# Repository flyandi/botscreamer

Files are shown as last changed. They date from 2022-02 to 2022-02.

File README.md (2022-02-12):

```
______  _____ _____ _____ _____ ______ _____  ___  ___  ___ ___________
| ___ \|  _  |_   _/  ___/  __ \| ___ \  ___|/ _ \ |  \/  ||  ___| ___ \
| |_/ /| | | | | | \ `--.| /  \/| |_/ / |__ / /_\ \| .  . || |__ | |_/ /
| ___ \| | | | | |  `--. \ |    |    /|  __||  _  || |\/| ||  __||    /
| |_/ /\ \_/ / | | /\__/ / \__/\| |\ \| |___| | | || |  | || |___| |\ \
\____/  \___/  \_/ \____/ \____/\_| \_\____/\_| |_/\_|  |_/\____/\_| \_|
```

This is the firmware and associated files for the Botscreamer as seen on Botgrinder TV.

The Botscreamer is a tiny 3W speaker system that reacts on the attitude of your quad and is light enough to be mounted on top of your lipo. Did I say it's loud? It's freaking loud! 

It comes with 4 pre-loaded sounds (simple 16bit PCM wav files) and even has a music maker mode that reacts on yaw (14 notes across 360 degrees).

See it in action here https://www.youtube.com/watch?v=8f52Pep6f3Y

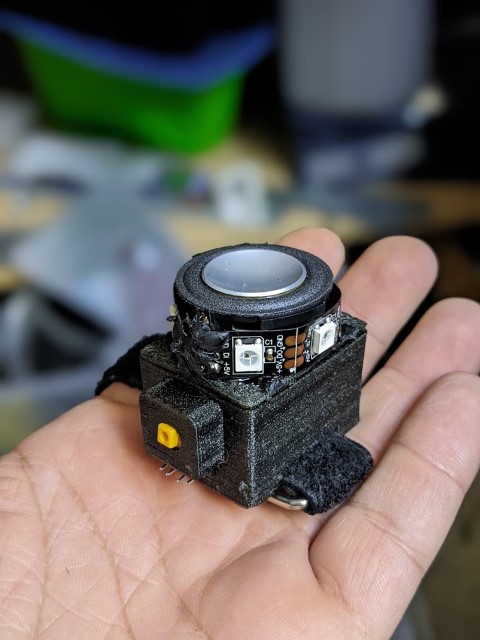
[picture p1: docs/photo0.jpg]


# Build it

Get the parts below:

1x ESP8266 Mini D1 (https://amzn.to/34F7Ud2)

1x MAX98357 I2S amplifier (https://amzn.to/3rzCkqs)

1x 4ohm/3w speaker with a large magnet (https://amzn.to/3Hz32op)

1x Tactile button 

1x 10k resistor (for the button)

1x 4-wire that connects to your FC

If you want LED lights, you also need a some WS8212 RGB LED's.

# Wire up

See the picture below how to wire everything up. This expects you used the parts above.

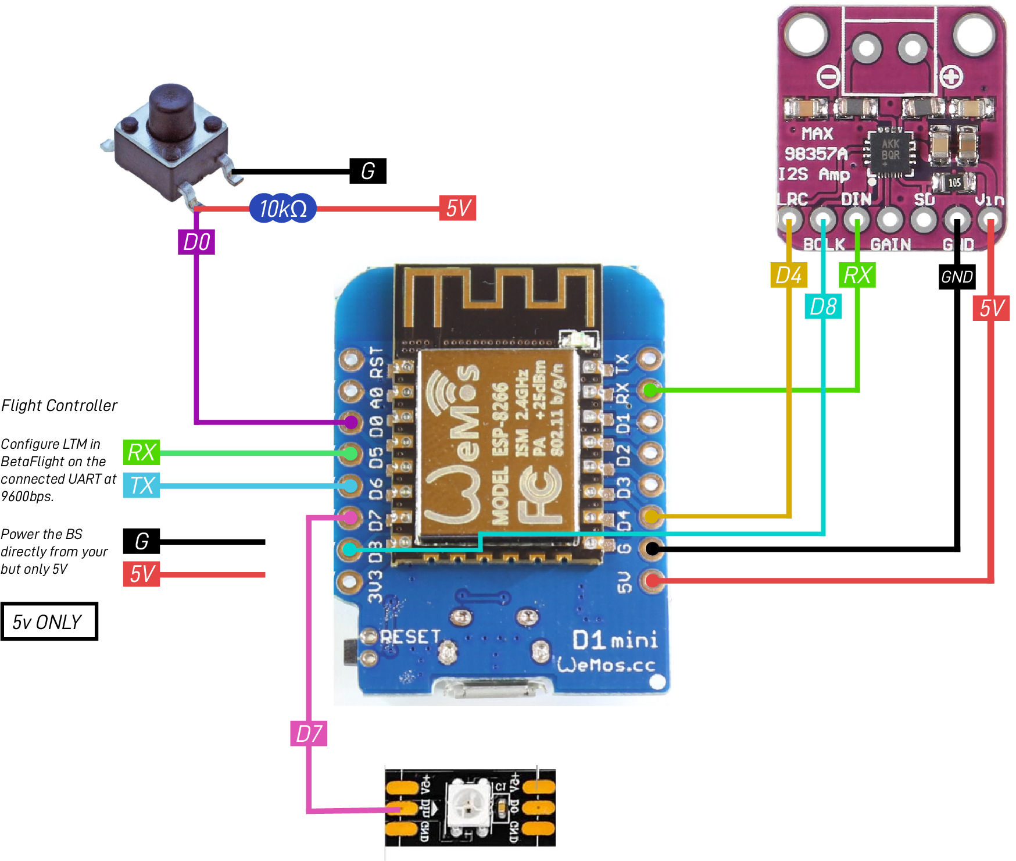
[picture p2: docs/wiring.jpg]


## WARNING

Make sure you power the ESP8266 ONLY with 5V or you will burn the ESP8266.

# Print it

There is a case in the `/3d` folder that fits all parts. Print with TPU95 with 20% infill to keep it light but still strong. The PCB material will stiffen it up. The case has cut outs on the bottom allowing you to use a up to 20mm strap.

# Deploy it

Use the Arduino IDE to deploy the code to the ESP8266 and use the SPIFFS tool to upload the files. RandomNerdTutorials has way better explanation than I could do, so head over to https://randomnerdtutorials.com/install-esp8266-filesystem-uploader-arduino-ide/ to learn more how to do that.

If you haven't actually installed the ESP8266 board definitions you need to use the Arduino IDE Platform Manager to install the ESP8266. Once again RDT has you covered at https://randomnerdtutorials.com/how-to-install-esp8266-board-arduino-ide/

There are a few libraries needed that can be downloaded via the Arduino IDE Library Manager:

+ Adafruit NeoPixel Library
+ ESP8266Audio Library

Once done, hook up your ESP8266 and upload it. 

# Configuration

There are some configurations that I explained in the code itself. Check it there.

# Fly it

There are 4 modes selectable through the button and the fifth mode is the music maker mode. Most modes have a minimum requirement of 1.2s in order to work which prevents false triggers. So you have to hold it for a least that time in order to enable.

| Mode | What | Comment | 
| ----  | --- | --- |
| 1 | Goat | Screams like a goat on roll (upside down) | 
| 2 | Human | Scary lady screaming like no other day on roll (upside down) |
| 3 | Duck | A rapid duck noise on roll (upside down) |
| 4 | Police | Police lights mode. Pitch forward to turn on sound and pitch backward to turn it off |
| 5 | Music Maker Mode | See below |

# Music Maker Mode

In Music Maker Mode the BS is playing a continues sound that can be modified using YAW. It plays 14 notes across the 360 degree. It runs on a static 100bpm so you have about 600ms to turn your quad to modify the sound which is plenty enough. 

`Make some tunez!`

# Audio Files

All audio files used are standard 16bit PCM encoded wave files with no compressions. Keep it short as the ESP8266 has about 2.5MB useable space. I recommend to keep it under 3s per audio file.

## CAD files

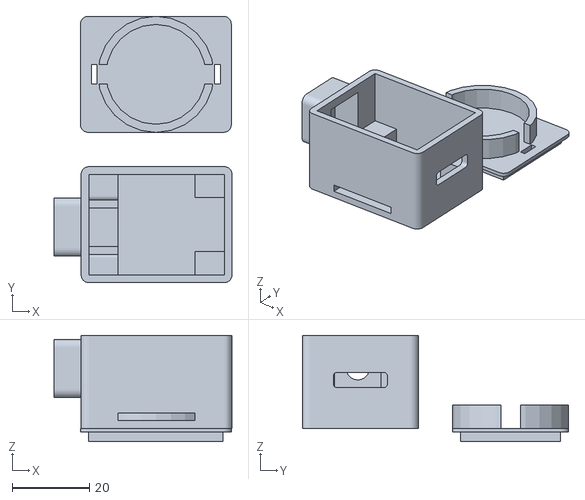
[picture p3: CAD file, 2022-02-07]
3d/case.stl
46.0 x 68.8 x 27.4

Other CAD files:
3d/case.skp

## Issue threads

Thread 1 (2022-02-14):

3d Files

jsimmo1, 2022-02-14:
Can't get get Cura or Sketchup to recognize the files.   Please check them.

flyandi, 2022-02-15:
Hmm.. I just loaded the STL straight into Cura without issues. I am on version 4.8.0

The Sketchup file is in 2021 and pre-2021 format.

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

jsimmo1, 2022-02-15:
Got it.   I had tried to download in Safari by using the download link file option instead of clicking on the stl file and then clicking on the download button which works.  Thanks for the response.

Closed 2022-02-15.

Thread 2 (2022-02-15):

Input voltage

mkvug, 2022-02-15:
Not really an issue, but I wasn't sure how else to ask and I figured this way others will see the answer. The ESP8266 says it takes 3.3v in, but you are showing 5v in. I can't find anything online that suggests the ESP8266 can handle 5v in. Am I missing something? Or are you actually using 3.3v?

flyandi, 2022-02-18:
Most ESP8266 dev boards expose a 5V pin .. but yeah I prefer the Wemos D1 because it's cheap and ready available and has the smallest footprint. They are smaller boards available but they are hard to come by.

Closed 2022-02-18.

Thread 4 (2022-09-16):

I cant make it work :( Photos and details

bloodf, 2022-09-16:
Hi, I loved the idea of the screamer. I've bought everything needed to do it, flashed the ESP, and soldered everything according to the schema. But When connected to the drone, it doesn't do anything. The ESP flashes blue (not a solid blue), and there is no sound :(

The 5V and G go
 from the drone to the board and the amplifier, the switch gets fed from the same connection using the resistor to the required port.

 The Arduino IDE flashes the board correctly and doesn't give any error.

 Is there any way to debug this?

 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

ray940, 2022-12-16:
Betaflight?

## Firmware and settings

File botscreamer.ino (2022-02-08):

/*
______  _____ _____ _____ _____ ______ _____  ___  ___  ___ ___________
| ___ \|  _  |_   _/  ___/  __ \| ___ \  ___|/ _ \ |  \/  ||  ___| ___ \
| |_/ /| | | | | | \ `--.| /  \/| |_/ / |__ / /_\ \| .  . || |__ | |_/ /
| ___ \| | | | | |  `--. \ |    |    /|  __||  _  || |\/| ||  __||    /
| |_/ /\ \_/ / | | /\__/ / \__/\| |\ \| |___| | | || |  | || |___| |\ \
\____/  \___/  \_/ \____/ \____/\_| \_\____/\_| |_/\_|  |_/\____/\_| \_|
ENVISIONED BY BOTGRINDER AND CREATED BY FLY&I
Learn more at https://github.com/flyandi/botscreamer or https://flyandi.net

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
THE SOFTWARE IS PROVIDED "AS IS", WITHOUT WARRANTY OF ANY KIND, EXPRESS OR
IMPLIED, INCLUDING BUT NOT LIMITED TO THE WARRANTIES OF MERCHANTABILITY,
FITNESS FOR A PARTICULAR PURPOSE AND NONINFRINGEMENT. IN NO EVENT SHALL THE
AUTHORS OR COPYRIGHT HOLDERS BE LIABLE FOR ANY CLAIM, DAMAGES OR OTHER LIABILITY,
WHETHER IN AN ACTION OF CONTRACT, TORT OR OTHERWISE, ARISING FROM, OUT OF OR IN
CONNECTION WITH THE SOFTWARE OR THE USE OR OTHER DEALINGS IN THE SOFTWARE.
*/

// -----------------------------------------------------------------------
// configuration, calibration

// Volume, 0 is off, 0.1 - 3.99 where 3.99 is the loudest possible
#define VOLUME 3.99

// Roll rate is used to determinated upside down flying
// Upside down is true when the value is < ROLL_LOW || > ROLL_HIGH,
#define ROLL_LOW -160 // -160 degree is the default
#define ROLL_HIGH 160 // 160 degree is the default

// Pitch rate is used to enable/disable certain functions
// Pitching forward enables it, and pitching backwards disables it
// Becomes true if it's within the range of min and max
#define PITCH_MIN 40
#define PITCH_MAX 60

// disable for production use
//#define DEBUG

// -----------------------------------------------------------------------
// DO NOT CHANGE ANYTHING BEYOND THIS PART
// ONLY IF YOU KNOW WHAT YOU DOING!

// includes
#include "ESP8266WiFi.h"
#include "AudioFileSourceSPIFFS.h"
#include "AudioFileSourcePROGMEM.h"
#include "AudioGeneratorRTTTL.h"
#include "AudioGeneratorWAV.h"
#include "AudioOutputI2S.h"
#include <SoftwareSerial.h>
#include <Adafruit_NeoPixel.h>

// ltm config
#define LTM_RX_PIN D5
#define LTM_TX_PIN D6
#include "ltm.h"

// button config
#define BUTTON_PIN D0
#define BUTTON_MIN 300

// led config
#define LED_PIN D7
#define LED_PIXELS 6
#define LED_BRIGHTNESS 255

#define LED_PROGRAM_DEFAULT 0
#define LED_PROGRAM_POLICE 1
#define LED_PROGRAM_HUE_HEADING 2

// on selector
#define ON_ROLL 0
#define ON_ROLL_TIMER 1200 // at least keep it 1.2 seconds upside down
#define ON_PITCH 1
#define ON_HEADING 2

// actual modes
//
struct
{
  char *file;
  uint8_t on;
  bool loop;
  uint8_t led_program;
  uint16_t led_time;
} MODES[] = {
    {"/goat.wav", ON_ROLL, false, LED_PROGRAM_DEFAULT, 50},
    {"/human.wav", ON_ROLL, false, LED_PROGRAM_DEFAULT, 50},
    {"/goose.wav", ON_PITCH, false, LED_PROGRAM_HUE_HEADING, 50},
    {"/police.wav", ON_PITCH, true, LED_PROGRAM_POLICE, 120},
    {"", ON_HEADING, true, LED_PROGRAM_HUE_HEADING, 50},
};

#define NUM_MODES 5
#define MODE_SYNTH 4

// synth
const char *SYNTH_NOTES[] = {
    "a",
    "b",
    "c",
    "d",
    "e",
    "f",
    "g",
    "a#",
    "b#",
    "c#",
    "d#",
    "e#",
    "f#",
    "g#"};

#define NUM_SYNTH_NOTES 14

// locals
AudioGeneratorWAV *wav;
AudioFileSourceSPIFFS *file;
AudioFileSourcePROGMEM *rts;
AudioOutputI2S *out;
AudioGeneratorRTTTL *rtttl;
Adafruit_NeoPixel pixels(LED_PIXELS, LED_PIN, NEO_GRB + NEO_KHZ800);

bool button_p = false;
bool led_enabled = true;
bool on_enabled = false;
uint8_t mode = 0;
uint16_t led_state = 0;
uint32_t button_t = 0;
uint32_t led_t = 0;
uint32_t on_t = 0;

#ifdef DEBUG
uint32_t debug_t = 0;
#endif

// setup
void setup()
{
  // start with pixels
  pixels.begin();
  pixels.show();
  pixels.setBrightness(LED_BRIGHTNESS);
  wipe(0xFF0000, true);

  // boot up
  WiFi.forceSleepBegin();
  Serial.begin(115200);
  pinMode(BUTTON_PIN, INPUT);
  pinMode(LED_BUILTIN, OUTPUT);
  out = new AudioOutputI2S();
  wav = new AudioGeneratorWAV();
  rtttl = new AudioGeneratorRTTTL();
  out->SetGain(VOLUME);
  ltm_begin();

  // cleanup
  delay(1000);
  wipe(0x00FF00, true);
  delay(1000);
}

// wipe
void wipe(uint32_t color, bool show)
{
  for (int i = 0; i < pixels.numPixels(); i++)
  {
    pixels.setPixelColor(i, color);
  }
  if (show)
  {
    pixels.show();
  }
}

// audio
void audio()
{
  if (rtttl->isRunning())
  {
    rtttl->stop();
  }
  if (wav->isRunning())
  {
    wav->stop();
  }
  if (mode != MODE_SYNTH)
  {
    file = new AudioFileSourceSPIFFS(MODES[mode].file);
    wav->begin(file, out);
  }
}

// cycle_mode
void cycle_mode()
{
  mode += 1;
  if (mode >= NUM_MODES)
  {
    mode = 0;
  }
  led_state = 0;
  on_enabled = false;
  audio();
}

// audio_loop
void audio_loop()
{
  if (mode == MODE_SYNTH)
  {
    if (rtttl->isRunning())
    {
      if (!rtttl->loop())
      {
        rtttl->stop();
      }
    }
    else
    {

      char tone[32];
      uint8_t note = map(LTM_DATA.heading, 0, 360, 0, NUM_SYNTH_NOTES - 1);
      if (note < 0 || note >= NUM_SYNTH_NOTES)
      {
        note = 0;
      }
      strcat(tone, "A:d=4,o=1,b=120:");
      strcat(tone, SYNTH_NOTES[note]);
#ifdef DEBUG
      Serial.printf("Note: heading %d / note %d %s\n", LTM_DATA.heading, note, SYNTH_NOTES[note]);
#endif
      rts = new AudioFileSourcePROGMEM(tone, strlen_P(tone));
      rtttl->begin(rts, out);
    }
    return;
  }

  if (wav->isRunning())
  {
    if (!wav->loop())
    {
      wav->stop();
      if (MODES[mode].loop && on_enabled)
      {
        audio();
      }
    }
  }
  else
  {

    if (on_enabled)
    {
      audio();
    }
  }
}

// process_loop
void process_loop()
{
  if (MODES[mode].on == ON_ROLL)
  {
    if ((LTM_DATA.roll > ROLL_HIGH && LTM_DATA.roll < 360) || (LTM_DATA.roll < ROLL_LOW && LTM_DATA.roll > -360))
    {
      if (on_t == 0)
      {
        on_t = millis();
      }
      else
      {
        if (millis() - on_t > ON_ROLL_TIMER)
        {
          on_enabled = true;
          on_t = 0;
        }
      }
    }
    else
    {
      on_enabled = false;
    }
  }

  if (MODES[mode].on == ON_PITCH)
  {
    if (!on_enabled && LTM_DATA.pitch > PITCH_MIN && LTM_DATA.pitch < PITCH_MAX)
    {
      on_enabled = true;
    }
    else if (on_enabled && LTM_DATA.pitch < -1 * PITCH_MIN && LTM_DATA.pitch > -1 * PITCH_MAX)
    {
      on_enabled = false;
    }
  }

#ifdef DEBUG
  if (millis() - debug_t > 250)
  {
    Serial.printf("P %d / R %d / H %d / ON %d\n", LTM_DATA.pitch, LTM_DATA.roll, LTM_DATA.heading, on_enabled);
    debug_t = millis();
  }
#endif
}

// led_loop
void led_loop()
{
  if (millis() - led_t > MODES[mode].led_time)
  {
    if (MODES[mode].led_program == LED_PROGRAM_POLICE)
    {
      wipe(0x000000, false);

      if (led_state == 0 || led_state == 2)
      {
        pixels.setPixelColor(0, 0xFF0000);
        pixels.setPixelColor(1, 0xFF0000);
        pixels.setPixelColor(2, 0xFF0000);
      }
      if (led_state == 4 || led_state == 6)
      {
        pixels.setPixelColor(3, 0x0000FF);
        pixels.setPixelColor(4, 0x0000FF);
        pixels.setPixelColor(5, 0x0000FF);
      }
      led_state += 1;
      if (led_state > 7)
      {
        led_state = 0;
      }
    }

    if (MODES[mode].led_program == LED_PROGRAM_DEFAULT)
    {
      if (wav->isRunning())
      {
        wipe(led_state % 2 != 0 ? pixels.ColorHSV((65536L / 32) * led_state) : 0x000000, false);
        led_state += 1;
        if (led_state > 512)
        {
          led_state = 0;
        }
      }
      else
      {
        wipe(0x000000, false);
      }
    }

    if (MODES[mode].led_program == LED_PROGRAM_HUE_HEADING)
    {
      wipe(pixels.ColorHSV((65536L / 360) * LTM_DATA.heading), false);
    }

    // general
    pixels.show();
    led_t = millis();
  }
}

// button_loop
void button_loop()
{
  bool button = !digitalRead(BUTTON_PIN);
  if (button && !button_p)
  {
    button_p = true;
    button_t = millis();
  }
  else if (!button && button_p)
  {
    button_p = false;
    if (millis() - button_t > BUTTON_MIN)
    {
      cycle_mode();
    }
  }
}

// loop
void loop()
{
  ltm_loop();
  audio_loop();
  process_loop();
  button_loop();
  led_loop();
}

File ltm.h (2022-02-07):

/*
 ____  __    _  _  __
(  __)(  )  ( \/ )/ _\
 ) _) / (_/\ )  //    \
(__)  \____/(__/ \_/\_/

This file is part of the FLYA Firmware. Learn more at https://flyandi.net/flya
Copyright 2021 FLY&I (FLYANDI.NET)

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
THE SOFTWARE IS PROVIDED "AS IS", WITHOUT WARRANTY OF ANY KIND, EXPRESS OR
IMPLIED, INCLUDING BUT NOT LIMITED TO THE WARRANTIES OF MERCHANTABILITY,
FITNESS FOR A PARTICULAR PURPOSE AND NONINFRINGEMENT. IN NO EVENT SHALL THE
AUTHORS OR COPYRIGHT HOLDERS BE LIABLE FOR ANY CLAIM, DAMAGES OR OTHER LIABILITY,
WHETHER IN AN ACTION OF CONTRACT, TORT OR OTHERWISE, ARISING FROM, OUT OF OR IN
CONNECTION WITH THE SOFTWARE OR THE USE OR OTHER DEALINGS IN THE SOFTWARE.
*/

#ifndef _H_LTM_
#define _H_LTM_

#include <SoftwareSerial.h>

#ifndef LTM_RX_PIN
#error LTM has no RX pin defined
#endif

#ifndef LTM_TX_PIN
#error LTM has no TX pin defined
#endif

#ifndef LTM_BAUD
#define LTM_BAUD 9600
#endif

enum
{
    LTM_IDLE,
    LTM_HEADER_START1,
    LTM_HEADER_START2,
    LTM_HEADER_MSGTYPE,
    LTM_HEADER_DATA
};

#define LTM_LONGEST_FRAME_LENGTH 18
#define LTM_GFRAMELENGTH 18
#define LTM_AFRAMELENGTH 10
#define LTM_SFRAMELENGTH 11
#define LTM_OFRAMELENGTH 18
#define LTM_NFRAMELENGTH 10
#define LTM_XFRAMELENGTH 10

const char *LTM_FLIGHT_MODES[] = {
    "Manual",
    "Rate",
    "Angle",
    "Horizon",
    "Acro",
    "Stabilized1",
    "Stabilized2",
    "Stabilized3",
    "Altitude Hold",
    "GPS Hold",
    "Waypoints",
    "Head free",
    "Circle",
    "RTH",
    "Follow me",
    "Land",
    "Fly by wire A",
    "Fly by wire B",
    "Cruise",
    "Unknown"};

static struct
{
    int pitch;
    int roll;
    int heading;
    uint16_t voltage;
    byte rssi;
    bool armed;
    bool failsafe;
    byte flightmode;

    int32_t latitude;
    int32_t longitude;
    int32_t altitude;
    uint8_t groundSpeed;
    int16_t hdop;
    uint8_t gpsFix;
    uint8_t gpsSats;

    int32_t homeLatitude;
    int32_t homeLongitude;

    uint8_t sensorStatus;
} LTM_DATA;

static SoftwareSerial ltm_serial;
static uint8_t ltm_buffer[LTM_LONGEST_FRAME_LENGTH];
static uint8_t ltm_state = LTM_IDLE;
static char ltm_frameType;
static byte ltm_frameLength;
static byte ltm_receiverIndex;

byte ltm_readByte(uint8_t offset)
{
    return ltm_buffer[offset];
}

int ltm_readInt(uint8_t offset)
{
    return (int)ltm_buffer[offset] + ((int)ltm_buffer[offset + 1] << 8);
}

uint16_t ltm_readInt_u16(uint8_t offset)
{
    return (uint16_t)ltm_buffer[offset] + ((uint16_t)ltm_buffer[offset + 1] << 8);
}

int32_t ltm_readInt32(uint8_t offset)
{
    return (int32_t)ltm_buffer[offset] + ((int32_t)ltm_buffer[offset + 1] << 8) + ((int32_t)ltm_buffer[offset + 2] << 16) + ((int32_t)ltm_buffer[offset + 3] << 24);
}

int ltm_to_attitude(int v)
{
    if (v > 32767)
    {
        v = -1 * (65535 - v);
    }
    return v;
}

static void ltm_begin()
{
    ltm_serial.begin(LTM_BAUD, SWSERIAL_8N1, LTM_RX_PIN, LTM_TX_PIN, false);
}

static void ltm_loop()
{
    if (ltm_serial.available())
    {

        char data = ltm_serial.read();

        if (ltm_state == LTM_IDLE)
        {
            if (data == '$')
            {
                ltm_state = LTM_HEADER_START1;
            }
        }
        else if (ltm_state == LTM_HEADER_START1)
        {
            if (data == 'T')
            {
                ltm_state = LTM_HEADER_START2;
            }
            else
            {
                ltm_state = LTM_IDLE;
            }
        }
        else if (ltm_state == LTM_HEADER_START2)
        {
            ltm_frameType = data;
            ltm_state = LTM_HEADER_MSGTYPE;
            ltm_receiverIndex = 0;

            switch (data)
            {

            case 'G':
                ltm_frameLength = LTM_GFRAMELENGTH;
                break;
            case 'A':
                ltm_frameLength = LTM_AFRAMELENGTH;
                break;
            case 'S':
                ltm_frameLength = LTM_SFRAMELENGTH;
                break;
            case 'O':
                ltm_frameLength = LTM_OFRAMELENGTH;
                break;
            case 'N': // inav
                ltm_frameLength = LTM_NFRAMELENGTH;
                break;
            case 'X': // inav
                ltm_frameLength = LTM_XFRAMELENGTH;
                break;
            default:
                ltm_state = LTM_IDLE;
            }
        }
        else if (ltm_state == LTM_HEADER_MSGTYPE)
        {
            if (ltm_receiverIndex == ltm_frameLength - 4)
            {

                if (ltm_frameType == 'A')
                {
                    LTM_DATA.pitch = ltm_to_attitude(ltm_readInt_u16(0));
                    LTM_DATA.roll = ltm_to_attitude(ltm_readInt_u16(2));
                    LTM_DATA.heading = ltm_to_attitude(ltm_readInt_u16(4));
                }

                if (ltm_frameType == 'S')
                {
                    LTM_DATA.voltage = ltm_readInt(0);
                    LTM_DATA.rssi = ltm_readByte(4);

                    byte raw = ltm_readByte(6);
                    LTM_DATA.flightmode = raw >> 2;
                }

                if (ltm_frameType == 'G')
                {
                    LTM_DATA.latitude = ltm_readInt32(0);
                    LTM_DATA.longitude = ltm_readInt32(4);
                    LTM_DATA.groundSpeed = ltm_readByte(8);
                    LTM_DATA.altitude = ltm_readInt32(9);

                    uint8_t raw = ltm_readByte(13);
                    LTM_DATA.gpsSats = raw >> 2;
                    LTM_DATA.gpsFix = raw & 0x03;
                }

                if (ltm_frameType == 'X')
                {
                    LTM_DATA.hdop = ltm_readInt(0);
                    LTM_DATA.sensorStatus = ltm_readByte(2);
                }

                ltm_state = LTM_IDLE;
                memset(ltm_buffer, 0, LTM_LONGEST_FRAME_LENGTH);
            }
            else
            {
                /*
                 * If no, put data into buffer
                 */
                ltm_buffer[ltm_receiverIndex++] = data;
            }
        }
    }
}

#endif // eof
